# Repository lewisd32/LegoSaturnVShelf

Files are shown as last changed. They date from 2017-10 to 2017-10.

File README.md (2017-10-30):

# Lego Saturn V Shelf

This is a shelf for the [Lego Saturn V (21309)](https://shop.lego.com/en-CA/LEGO-NASA-Apollo-Saturn-V-21309),
made mostly out of Lego, with some 3D printed parts. Inspired by the [Saturn V Mobile Launcher Platform](http://www.savethelut.org/MLDocs/ap4-KSC-67PC-368.jpg), and it's gantry.
 
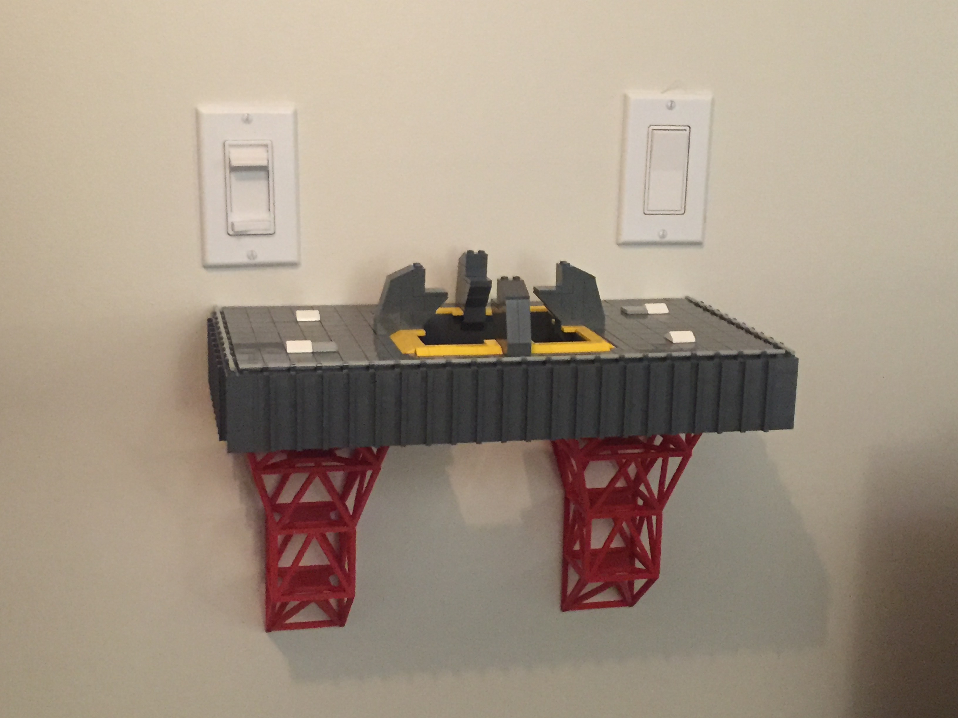
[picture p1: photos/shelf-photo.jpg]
photo of shelf

 
The only 3D printed parts are the screw mounts on the back, and the supports
underneath that are styled like the Saturn V gantry. Everything else is Lego.

## Lego Model

The model ([SaturnVShelf.lxf](SaturnVShelf.lxf)) can be opened with
[Lego Digital Designer](http://ldd.lego.com/en-us/)
4.3.

The included BOM ([SaturnVShelf-BOM.xlsx](SaturnVShelf-BOM.xlsx)) exported by LDD lists the pieces
needed. You can order most of the parts from [Pick-A-Brick](https://shop.lego.com/Pick-a-Brick).
The remainder can be had from [BrickLink](bricklink.com).

When I ordered pieces for this (June 2017) everything was available on Pick-A-Brick except for the
flat yellow tiles around the hole in the top. These were available on BrickLink.

## 3D Printing

Printing the gantry was, admittedly, a challenge. By separating each gantry
into 4 pieces, and further separating one of these pieces into 3 more, I was
able to print it successfully.

All files for 3D printing are within the [3D Printing](3DPrinting) folder. All the models
are done with [OpenSCAD](www.openscad.org).

- [shelf.scad](3DPrinting/shelf.scad) - Main rendering, and modules for all the gantry parts. 
- [rocket-bottom.scad](3DPrinting/rocket-bottom.scad) - Rough rendering of the bottom of the Lego Saturn V model. Only used for visualizing how the shelf will look.
- [screwmount.scad](3DPrinting/screwmount.scad) - Model for the part that holds the screws at the back of the shelf.

### Models

The [3DPrinting/prints](3DPrinting/prints) folder has the models for the gantry broken into individual parts for printing.
Both the OpenSCAD source file (`.scad`) and exported model (`.stl`) are included, so you shouldn't need OpenSCAD unless you
want to modify the models.
 
Gantry Layer 1 is split into 3 prints because I was unable to get it to print successfully as one piece. Your millage may vary.

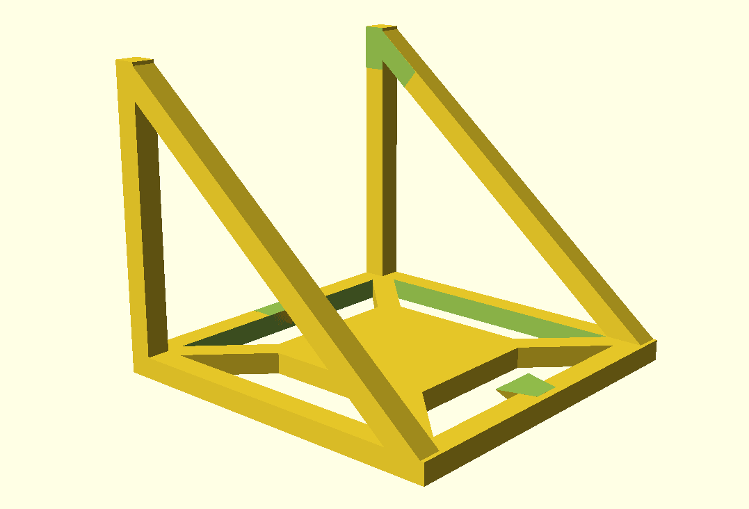
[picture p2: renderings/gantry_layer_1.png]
Gantry layer 1

[gantry_layer_1.stl](3DPrinting/prints/gantry_layer_1.stl)/[scad](3DPrinting/prints/gantry_layer_1.scad) - Lowest part of gantry, with center parts cut of for easier printing. 

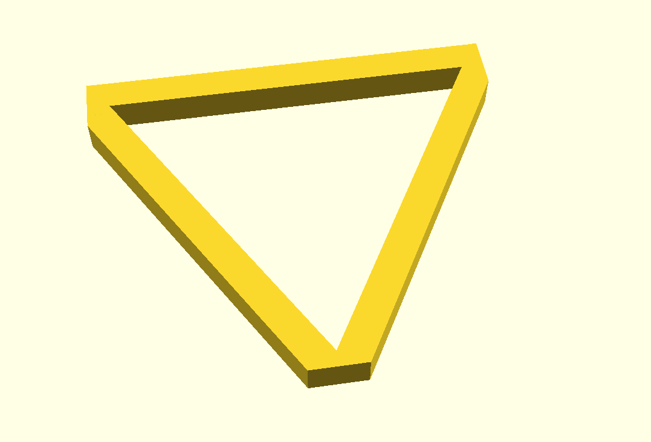
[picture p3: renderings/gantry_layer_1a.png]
Gantry layer 1 part a

[gantry_layer_1a.stl](3DPrinting/prints/gantry_layer_1a.stl)/[scad](3DPrinting/prints/gantry_layer_1a.scad) - One of the center parts.

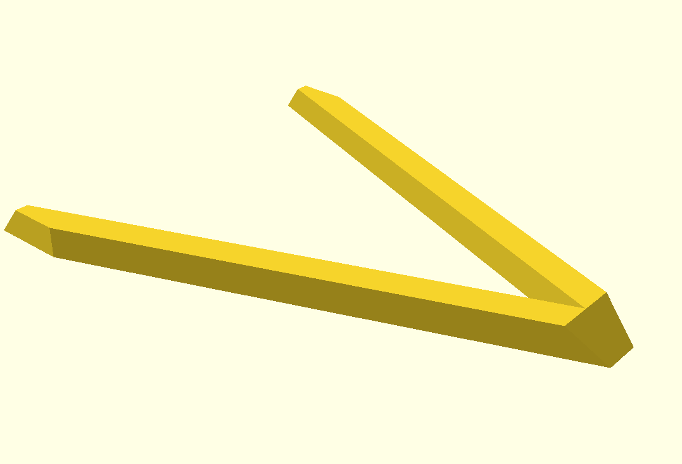
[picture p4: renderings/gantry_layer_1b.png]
Gantry layer 1 part b

[gantry_layer_1b.stl](3DPrinting/prints/gantry_layer_1b.stl)/[scad](3DPrinting/prints/gantry_layer_1b.scad) - The other center part.

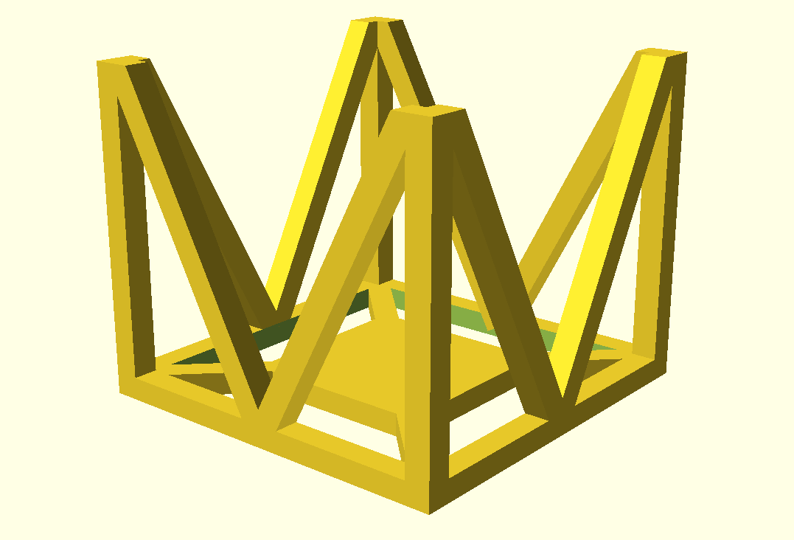
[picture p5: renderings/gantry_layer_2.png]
Gantry layer 2

[gantry_layer_2.stl](3DPrinting/prints/gantry_layer_2.stl)/[scad](3DPrinting/prints/gantry_layer_2.scad) - 2nd from bottom part of shelf. Straight sides, no angle. 

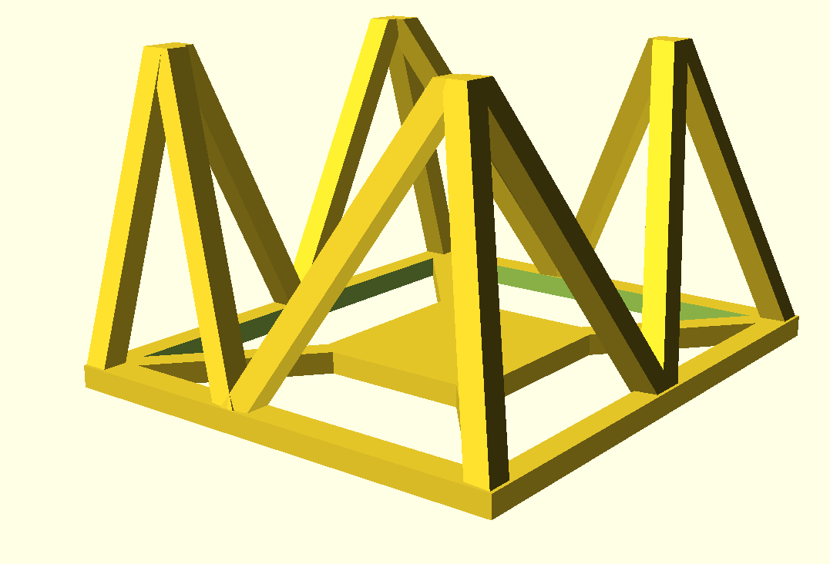
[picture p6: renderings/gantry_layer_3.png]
Gantry layer 2

[gantry_layer_3.stl](3DPrinting/prints/gantry_layer_3.stl)/[scad](3DPrinting/prints/gantry_layer_3.scad) - 2nd from top part of shelf, angled sides.

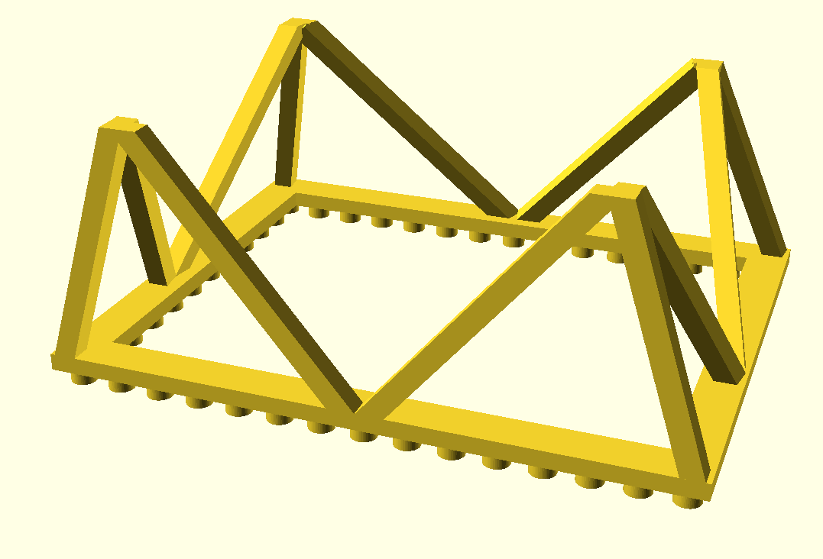
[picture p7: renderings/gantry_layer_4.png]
Gantry layer 3

[gantry_layer_4.stl](3DPrinting/prints/gantry_layer_4.stl)/[scad](3DPrinting/prints/gantry_layer_4.scad) - Top part of the gantry, with studs for mounting to the bottom of the shelf, and angled sides.

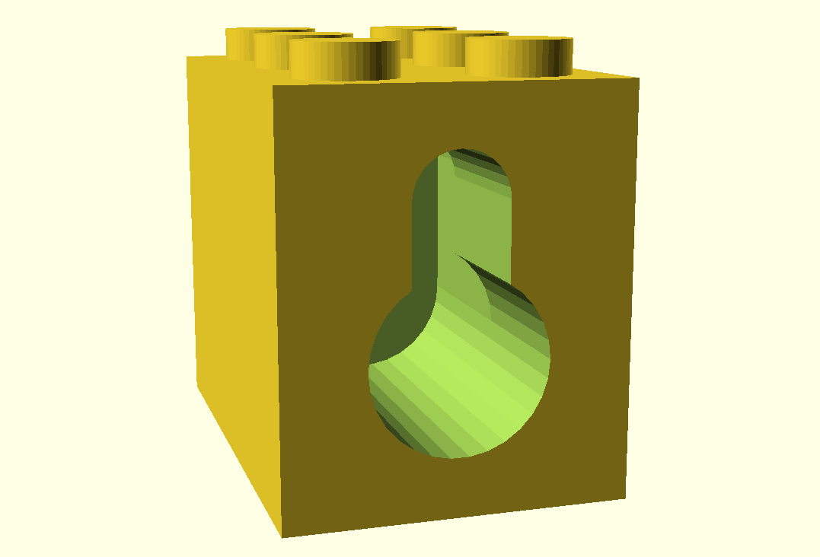
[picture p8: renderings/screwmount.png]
Screw mount

[screwmount.stl](3DPrinting/prints/screwmount.stl)/[scad](3DPrinting/prints/screwmount.scad) - Screw mounts for the back of the shelf. You'll need 3 of these.

### Printing

I printed this with ABS. This allows for using acetone to glue the different parts together quite strongly.

You'll need to figure out the best settings for your printer, but this is what I used:
- 0.4mm nozzle
- 0.1mm layers
- 100% infill
- 2.0mm wall thickness
- 1.2mm top/bottom thickness
- Inner before outer walls
- Support
  - Everywhere
  - 10 degree overhang angle
  - 15% density
  - 0.1mm Z distance (top and bottom)
  - 0.7mm X/Y distance 
- Raft
  - 5mm extra margin
  - 0.1mm air gap
  - 0.05mm initial z layer overlap
  - 2 top layers

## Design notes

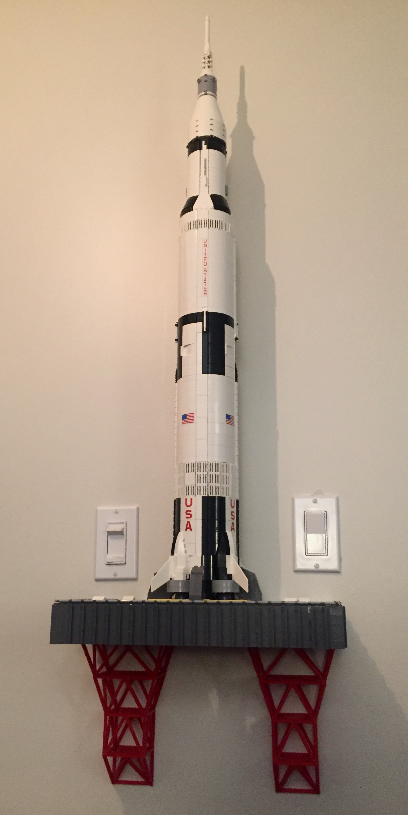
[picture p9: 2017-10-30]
photos/shelf-and-SaturnV-photo.jpg

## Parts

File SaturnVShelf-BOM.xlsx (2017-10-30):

Brick | Name | Picture | Part | Color code | Quantity
 | BRICK 1X1 |  | 3005 | 21 - Bright Red | 6
 | BRICK 1X1 |  | 3005 | 199 - Dark Stone Grey | 8
 | BRICK 1X2 |  | 3004 | 21 - Bright Red | 9
 | BRICK 1X2 |  | 3004 | 199 - Dark Stone Grey | 17
 | BRICK 1X3 |  | 3622 | 21 - Bright Red | 2
 | BRICK 1X2X2 |  | 3245 | 24 - Bright Yellow | 3
 | BRICK 2X2 |  | 3003 | 21 - Bright Red | 10
 | BRICK 2X2 |  | 3003 | 199 - Dark Stone Grey | 20
 | BRICK 1X4 |  | 3010 | 21 - Bright Red | 8
 | BRICK 1X4 |  | 3010 | 199 - Dark Stone Grey | 2
 | BRICK 2X3 |  | 3002 | 21 - Bright Red | 12
 | BRICK 2X3 |  | 3002 | 199 - Dark Stone Grey | 63
 | BRICK 1X6 |  | 3009 | 21 - Bright Red | 8
 | BRICK 1X6 |  | 3009 | 199 - Dark Stone Grey | 43
 | BRICK 2X4 |  | 3001 | 21 - Bright Red | 170
 | BRICK 2X4 |  | 3001 | 199 - Dark Stone Grey | 154
 | BRICK 1X8 |  | 3008 | 21 - Bright Red | 3
 | BRICK 1X8 |  | 3008 | 199 - Dark Stone Grey | 2
 | BRICK 1X10 |  | 6111 | 21 - Bright Red | 8
 | BRICK 1X10 |  | 6111 | 199 - Dark Stone Grey | 2
 | BRICK 2X6 |  | 44237 | 21 - Bright Red | 2
 | BRICK 2X6 |  | 44237 | 199 - Dark Stone Grey | 23
 | ROOF TILE 1X1X2/3, PC |  | 50746 | 24 - Bright Yellow | 8
 | ROOF TILE 1 X 2 X 2/3, ABS |  | 85984 | 1 - White | 16
 | ROOF TILE 1 X 2 X 2/3, ABS |  | 85984 | 24 - Bright Yellow | 24
 | ROOF TILE 2X2/45 INV. |  | 3660 | 199 - Dark Stone Grey | 12
 | ROOF TILE 1X2X3/73° |  | 4460 | 199 - Dark Stone Grey | 8
 | ROOF TILE 2X3/25° |  | 3298 | 199 - Dark Stone Grey | 4
 | FLAT TILE 1X1 |  | 3070 | 24 - Bright Yellow | 4
 | FLAT TILE 1X1 |  | 3070 | 199 - Dark Stone Grey | 16
 | PLATE 1X1 |  | 3024 | 1 - White | 2
 | PLATE 1X1 |  | 3024 | 199 - Dark Stone Grey | 72
 | FLAT TILE 1X2 |  | 3069 | 24 - Bright Yellow | 28
 | FLAT TILE 1X2 |  | 3069 | 199 - Dark Stone Grey | 20
 | PLATE 1X2 |  | 3023 | 21 - Bright Red | 6
 | PLATE 1X2 |  | 3023 | 199 - Dark Stone Grey | 14
 | FLAT TILE 1X4 |  | 2431 | 199 - Dark Stone Grey | 1
 | FLAT TILE 2X2 |  | 3068 | 194 - Medium Stone Grey | 4
 | FLAT TILE 2X2 |  | 3068 | 199 - Dark Stone Grey | 176
 | PLATE 2X2 |  | 3022 | 21 - Bright Red | 6
 | PLATE 2X2 |  | 3022 | 199 - Dark Stone Grey | 4
 | PLATE 1X4 |  | 3710 | 1 - White | 2
 | PLATE 1X4 |  | 3710 | 21 - Bright Red | 4
 | PLATE 1X4 |  | 3710 | 199 - Dark Stone Grey | 29
 | FLAT TILE 1X6 |  | 6636 | 199 - Dark Stone Grey | 23
 | PLATE 1X6 |  | 3666 | 1 - White | 2
 | PLATE 1X6 |  | 3666 | 21 - Bright Red | 12
 | PLATE 1X6 |  | 3666 | 199 - Dark Stone Grey | 14
 | PLATE 2X4 |  | 3020 | 199 - Dark Stone Grey | 4
 | PLATE 1X8 |  | 3460 | 1 - White | 2
 | PLATE 1X12 |  | 60479 | 1 - White | 3
 | PLATE 1X1 W. HOLDER |  | 4085 | 199 - Dark Stone Grey | 65
 | PLATE 1X2 WITH SLIDE |  | 32028 | 199 - Dark Stone Grey | 123
 | PLATE 1X2 W. STICK |  | 2540 | 1 - White | 24
 | LIGHT SWORD - BLADE |  | 30374 | 194 - Medium Stone Grey | 23
Total:

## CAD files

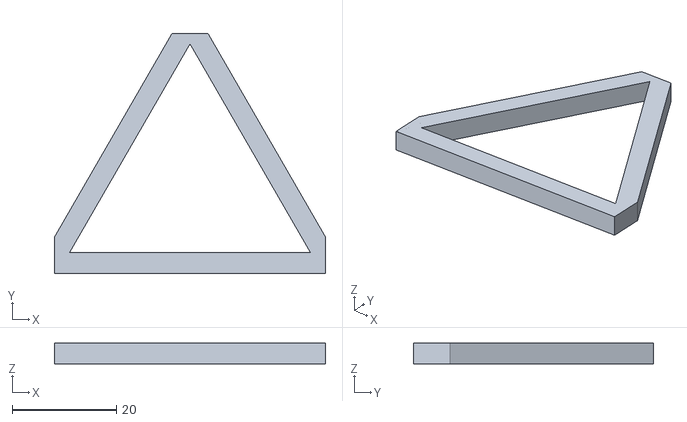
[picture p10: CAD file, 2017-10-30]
3DPrinting/prints/gantry_layer_1a.stl
52.0 x 46.0 x 4.01

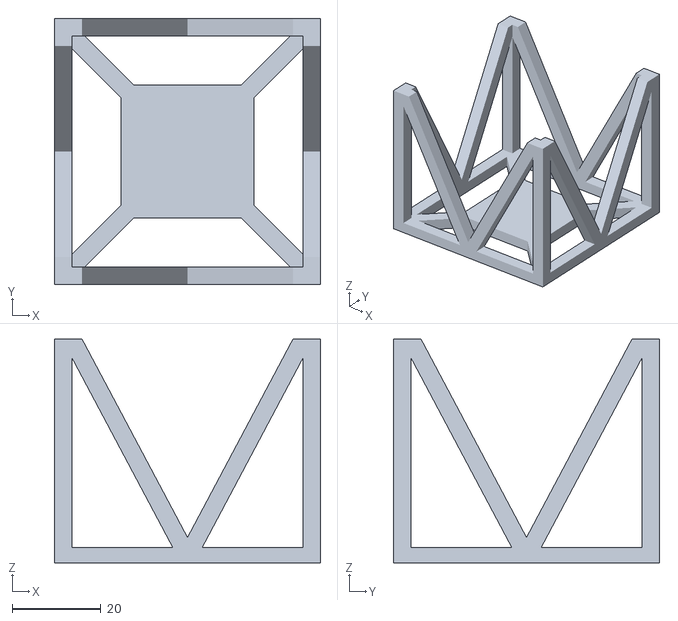
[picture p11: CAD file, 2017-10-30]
3DPrinting/prints/gantry_layer_2.stl
60.0 x 60.0 x 50.5

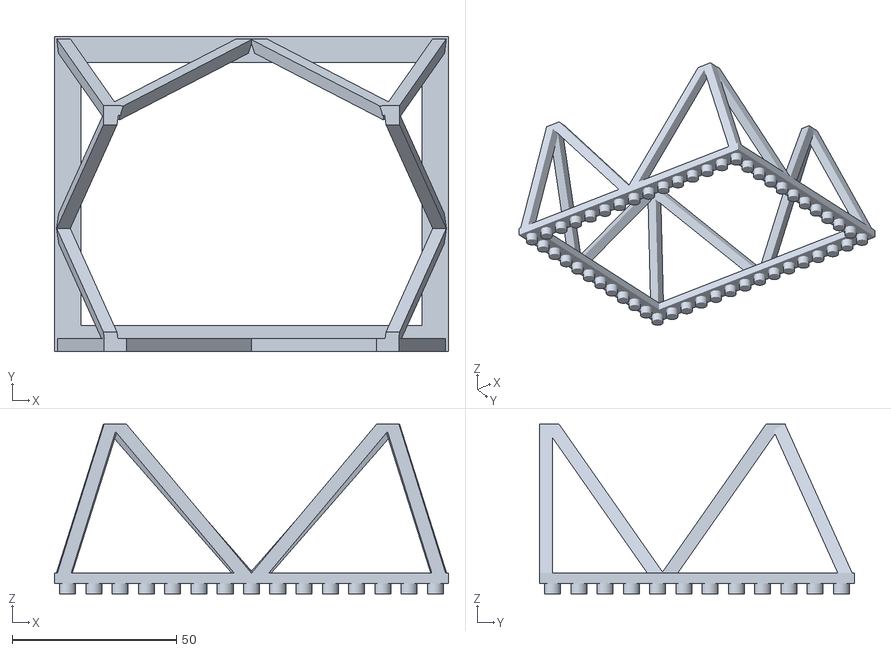
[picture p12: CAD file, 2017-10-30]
3DPrinting/prints/gantry_layer_4.stl
120.0 x 96.0 x 51.7

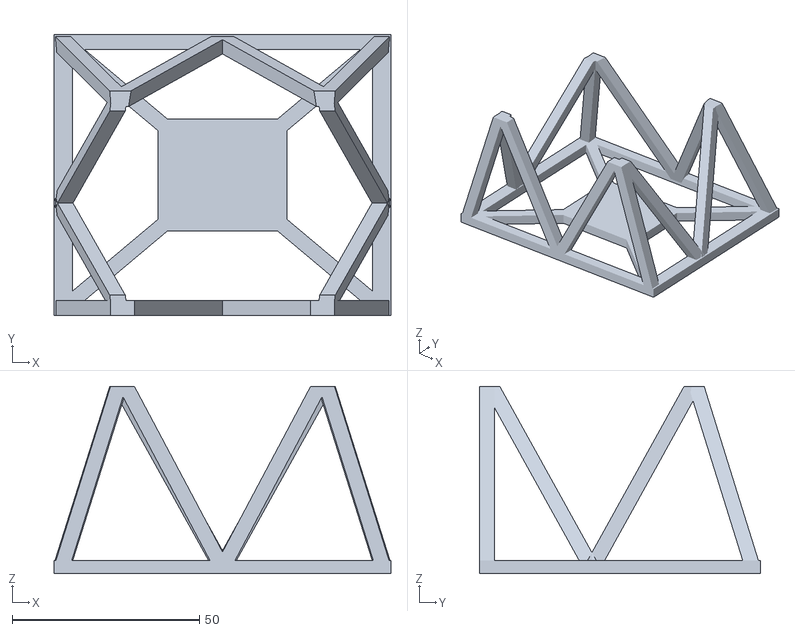
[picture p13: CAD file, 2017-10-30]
3DPrinting/prints/gantry_layer_3.stl
90.0 x 75.0 x 50.0

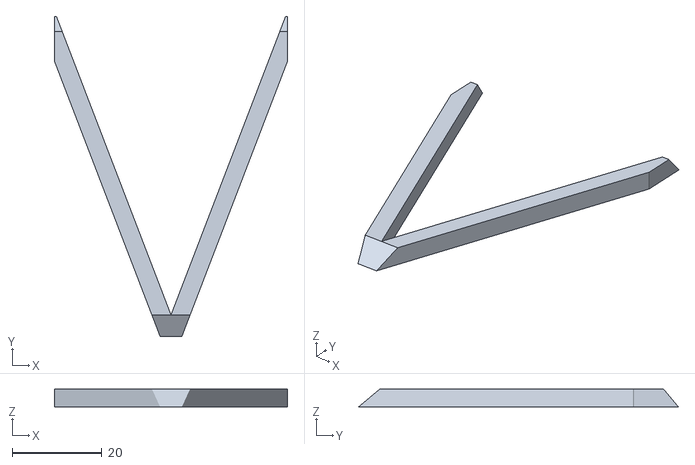
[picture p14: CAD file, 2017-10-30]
3DPrinting/prints/gantry_layer_1b.stl
52.0 x 71.4 x 4.00

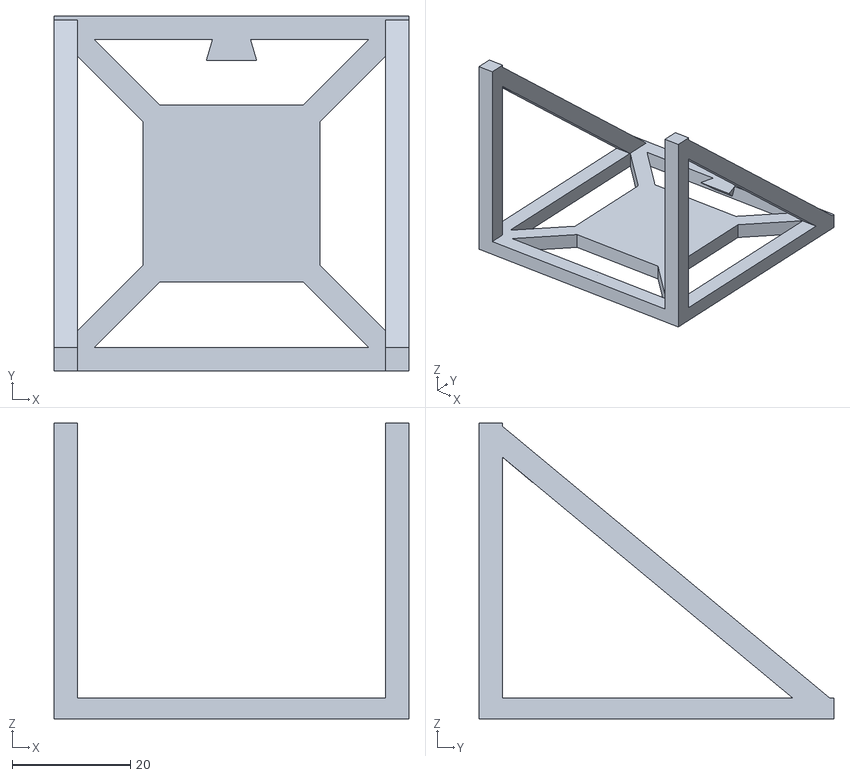
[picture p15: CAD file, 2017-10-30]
3DPrinting/prints/gantry_layer_1.stl
60.0 x 60.0 x 50.0

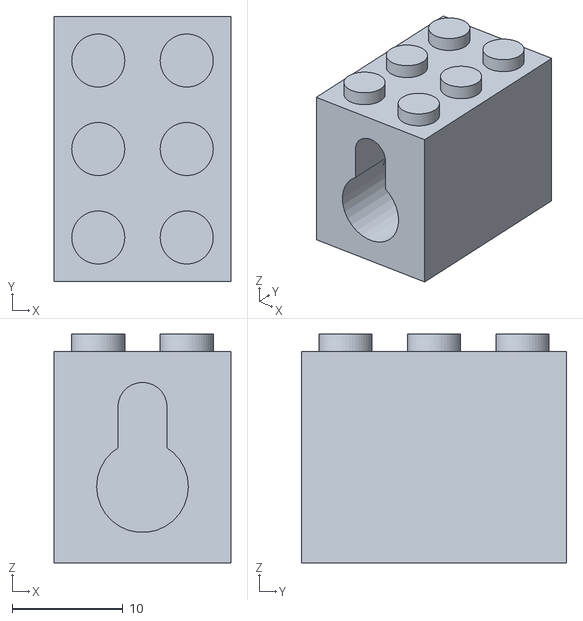
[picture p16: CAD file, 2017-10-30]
3DPrinting/prints/screwmount.stl
16.0 x 24.0 x 20.7

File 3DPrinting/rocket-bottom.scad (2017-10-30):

use <lib/centered_cube.scad>
use <lib/torus.scad>

translate([0,0,-1.1])
ccube([93,93,1]);

module nozzle() {
    color([.2,.2,.2])
    cylinder(d1=40, d2=16+(40-16)*((40-16)/40), h=16);

    color([.35,.35,.35])
    translate([0,0,16])
    torus(34, 5);

    color([.5,.5,.5])
    translate([0,0,16])
    cylinder(d1=16+(40-16)*((40-16)/40), d2=16, h=40-16);
}


module nozzle_and_fin() {
    nozzle();

    color([.8, .8, .8])
    translate([0,0,41.6]) {
        intersection() {
            cylinder(d=38, h=16);
            translate([0,0,-1])
            ccube([50,50,20], centered=[0,1,0]);
        }
        rotate([0,0,180])
        ccube([4,38,16], centered=[0,1,0]);
    }
    
    color([0,0,0])
    translate([0,0,40])
    ccube([16, 16, 8], centered=[1,1,0]);


    // fin mount
    color([1,1,1])
    translate([0,0,57.6])
    resize([38,32,64])
    cylinder(d1=32, d2=16, h=64);

    // fin
    color([1,1,1])
    translate([18,0,65.6])
    rotate([90,0,0])
    translate([0,0,-0.8])
    linear_extrude(height=1.6) {
        polygon(points=[
            [0,0],
            [3,-8],
            [32, -22],
            [32, -6],
            [0, 24]
        ]);
    }
}

module rocket_bottom() {
    nozzle();
    color([.8, .8, .8])
    translate([0,0,40])
    cylinder(d=16, h=18);

    for (r = [0:1:3]) {
        rotate([0,0,r*90])
        translate([42.5,0,0])
        nozzle_and_fin();
    }
    
    // bottom of fuel tank
    color([1,1,1])
    translate([0,0,58])
    cylinder(d=80, h=32);
}

rocket_bottom();

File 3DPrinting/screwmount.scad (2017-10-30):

use <lib/centered_cube.scad>
use <lib/lego_brick_builder.scad>

screw_head_diameter=8.1 + 0.1;
screw_head_height=3.5;
screw_thread_diameter=4.25 + 0.1;

screw_ledge_depth=7.5;

FLU = 1.6; // Fundamental Lego Unit = 1.6 mm

BRICK_WIDTH = 5*FLU; // basic brick width
BRICK_HEIGHT = 6*FLU;
PLATE_HEIGHT = 2*FLU; // basic plate height

difference() {
    union() {
        translate([0,0,PLATE_HEIGHT])
        ccube([BRICK_WIDTH*2, BRICK_WIDTH*3, BRICK_HEIGHT*2 - PLATE_HEIGHT], centered=[1,0,0]);
        
        translate([-BRICK_WIDTH,0,-0.3])
        brick(2,3,1.25,1);

        translate([-BRICK_WIDTH,0,BRICK_HEIGHT*2])
        brick(2,3,0,0);
    }
    
    translate([0,0,-0.31])
    ccube([BRICK_WIDTH*2+1, BRICK_WIDTH*3+1, 0.4], centered=[1,0,0]);

    // hole for screw thread
    hull() {
        translate([0,-0.01,BRICK_HEIGHT*2-5])
        rotate([-90,0,0])
        cylinder(d=screw_thread_diameter+0.1, h=screw_ledge_depth+screw_head_height+5, $fs=0.5);

        translate([0,-0.01,7])
        rotate([-90,0,0])
        cylinder(d=screw_thread_diameter+0.1, h=screw_ledge_depth+screw_head_height+5, $fs=0.5);
    }

    // inner hole for screw head
    hull() {
        translate([0,screw_ledge_depth,BRICK_HEIGHT*2-5])
        rotate([-90,0,0])
        cylinder(d=screw_head_diameter+0.1, h=screw_head_height+5, $fs=0.5);

        translate([0,screw_ledge_depth,7])
        rotate([-90,0,0])
        cylinder(d=screw_head_diameter+0.1, h=screw_head_height+5, $fs=0.5);
    }
    
    // outer hole for screw head
        translate([0,-0.01,7])
        rotate([-90,0,0])
        cylinder(d=screw_head_diameter+0.1, h=screw_ledge_depth+screw_head_height+5, $fs=0.5);

}


/*
translate([-FLU*2.5,FLU*2.5,-0.1])
cylinder(d=FLU*3, h=FLU, $fn=50);

*/

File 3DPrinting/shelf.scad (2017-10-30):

use <lib/centered_cube.scad>
use <lib/lego_brick_builder.scad>
use <rocket-bottom.scad>

do_slow=true;

FLU = 1.6; // Fundamental Lego Unit = 1.6 mm

BRICK_WIDTH = 5*FLU; // basic brick width
BRICK_HEIGHT = 6*FLU;
PLATE_HEIGHT = 2*FLU; // basic plate height

rib_thickness=3;
rib_depth=4;
rib_spacing=20.5;

lip_thinckness=3;
lip_depth=rib_depth;

platform_x = 366;
platform_y = 180;
platform_z = 50;

module platform_with_ribs() {
    color([.8,.8,.8]) {

    ccube([platform_x,platform_y,platform_z], centered=[1,1,0]);
        
    // fill in the ribs at the back of the platform so they 
    // don't gouge the wall.
    translate([0,-platform_y/2-rib_depth,0])
    ccube([platform_x,rib_depth*2,platform_z], centered=[1,0,0]);

    // corners
    for (x = [-platform_x/2, platform_x/2]) {
        for (y = [-platform_y/2, platform_y/2]) {
            translate([x, y, 0])
            ccube([rib_depth*2,rib_depth*2,platform_z], centered=[1,1,0]);
        }
    }

    for (y = [-platform_y/2, platform_y/2]) {
        // top and bottom lip at front of platform
        for (z = [0, platform_z-lip_thinckness]) {
            translate([0,y,z])
            ccube([platform_x,lip_depth*2,lip_thinckness], centered=[1,1,0]);
        }

        // ribs at front (and back) of platform
        for (x = [-platform_x/2:rib_spacing:platform_x/2]) {
            translate([x, y, 0])
                ccube([rib_thickness,rib_depth*2,platform_z], centered=[1,1,0]);
        }
    }

    for (x = [-platform_x/2, platform_x/2]) {
        // top and bottom lip at sides of platform
        for (z = [0, platform_z-lip_thinckness]) {
            translate([x,0,z])
            ccube([lip_depth*2,platform_y,lip_thinckness], centered=[1,1,0]);
        }

        // ribs on sides of platform
        for (y = [-platform_y/2:rib_spacing:platform_y/2]) {
            translate([x, y, 0])
                ccube([rib_depth*2,rib_thickness,platform_z], centered=[1,1,0]);
        }
    }

    }
}

module wedge() {
    hull() {
        cube([1,1,0.1]);
        cube([0.1,1,1]);
    }
}

module lego_double_wedge() {
    translate([-BRICK_WIDTH, 0, 0])
    brick(2,1,1,1);
    *translate([-BRICK_WIDTH, 0, 0])
    brick(1,1,1,1);
    translate([BRICK_WIDTH, 0, 0])
    resize([BRICK_WIDTH, BRICK_WIDTH, PLATE_HEIGHT])
    wedge();
    
    translate([BRICK_WIDTH-0.5, 0, 0])
    cube([1,BRICK_WIDTH,1]);
}

module lego_wedge() {
    brick(1,4,1,1);
    translate([BRICK_WIDTH, 0, 0])
    resize([BRICK_WIDTH*1, BRICK_WIDTH*4, PLATE_HEIGHT])
    wedge();
    
    translate([BRICK_WIDTH-0.5, 0, 0])
    cube([1,BRICK_WIDTH*4,1]);
}

module lego_corner_wedge() {
    translate([-BRICK_WIDTH, 0, 0])
    difference() {
        brick(2,1,1,1);
        translate([1.6+BRICK_WIDTH,6,-1])
        cube([4.8,3,2.6]);
    }
    
    difference() {
        brick(1,2,1,1);
        translate([-0.5,1.6,-1])
        cube([3,4.8,2.6]);
    }
    
    
    translate([BRICK_WIDTH, 0, 0])
    resize([BRICK_WIDTH*1, BRICK_WIDTH*2, PLATE_HEIGHT])
    wedge();
    
    translate([-BRICK_WIDTH, 0, 0])
    rotate([0,0,-90])
    resize([BRICK_WIDTH*1, BRICK_WIDTH*2, PLATE_HEIGHT])
    wedge();

    intersection() {
        translate([BRICK_WIDTH, -BRICK_WIDTH, 0])
        resize([BRICK_WIDTH*1, BRICK_WIDTH*1, PLATE_HEIGHT])
        wedge();
        
        translate([BRICK_WIDTH, 0, 0])
        rotate([0,0,-90])
        resize([BRICK_WIDTH*1, BRICK_WIDTH*1, PLATE_HEIGHT])
        wedge();
    }
    
    translate([BRICK_WIDTH-0.5, 0, 0])
    cube([1,BRICK_WIDTH*2,1]);
    
    translate([-BRICK_WIDTH, -0.5, 0])
    cube([BRICK_WIDTH*2, 1,1]);

}

module yellow_outlines() {
    for (r = [0:1:3]) {
        rotate([0,0,r*90])
        translate([55,-55,platform_z]) {
            corner_d=5;
            w=50;
            l=10;
            t=7;
            h=1;
            o=1;
            
            color([.8,.8,0])
            translate([0, BRICK_WIDTH, 0])
            lego_wedge();
                
            color([.85,.85,0])
            translate([0, BRICK_WIDTH*5, 0])
            lego_double_wedge();

            color([.85,.85,0])
            translate([0, -BRICK_WIDTH, 0])
            lego_corner_wedge();

            color([.85,.85,0])
            mirror([1,1,0])
            translate([0, BRICK_WIDTH*5, 0])
            lego_double_wedge();

            color([.8,.8,0])
            mirror([1,1,0])
            translate([0, BRICK_WIDTH, 0])
            lego_wedge();
        }
    }
}

module flame_channels() {
    for (r = [0:1:3])
    rotate([0,0,r*90])
    translate([BRICK_WIDTH*4,BRICK_WIDTH*4,-1])
    ccube([BRICK_WIDTH*6, BRICK_WIDTH*6,200], centered=[1,1,0]);
    
    hull() {
        translate([0,0,-1])
        ccube([BRICK_WIDTH*14, BRICK_WIDTH*14, 1], centered=[1,1,0]);
        translate([0,0,platform_z-PLATE_HEIGHT])
        ccube([BRICK_WIDTH*10, BRICK_WIDTH*10, 0.01], centered=[1,1,0]);
    }
    translate([0,0,platform_z-PLATE_HEIGHT])
    ccube([BRICK_WIDTH*10, BRICK_WIDTH*10, PLATE_HEIGHT*2], centered=[1,1,0]);
}

module hold_down_arm() {
    translate([BRICK_WIDTH*5,-BRICK_WIDTH,platform_z]) {
        color([.8,.8,.8])
        brick(4, 2, 3);

        color([1,1,1])
        translate([BRICK_WIDTH,0,BRICK_HEIGHT])
        brick(3, 2, 3);
        color([.9,.9,.9])
        translate([-BRICK_WIDTH,0,BRICK_HEIGHT])
        brick(2, 2, 3);
        

        color([.8,.8,.8])
        translate([-BRICK_WIDTH*2,0,BRICK_HEIGHT*2])
        brick(2, 2, 3);
        color([.9,.9,.9])
        translate([0,0,BRICK_HEIGHT*2])
        brick(3, 2, 3);
        
        color([.8,.8,.8])
        translate([-BRICK_WIDTH*2,0,BRICK_HEIGHT*3])
        brick(1, 2, 1, 1);
        color([.7,.7,.7])
        translate([-BRICK_WIDTH,0,BRICK_HEIGHT*3])
        brick(2, 2, 1, 1);
        color([1,1,1])
        translate([BRICK_WIDTH*1,0,BRICK_HEIGHT*3])
        brick(1, 2, 3);
        color([.8,.8,.8])
        translate([BRICK_WIDTH*2,0,BRICK_HEIGHT*3])
        brick(1, 2, 3);

        color([.8,.8,.8])
        translate([0,0,BRICK_HEIGHT*3+PLATE_HEIGHT])
        brick(1, 2, 2);
        
        color([.9,.9,.9])
        translate([0,0,BRICK_HEIGHT*4])
        brick(3, 2, 3);
    }
}

module hold_down_arms() {
    for (r = [0:1:3])
    rotate([0,0,r*90])
    hold_down_arm();
}

module launch_platform() {
    difference() {
        union() {
            platform_with_ribs();
            if (do_slow) {
                lego_plate();
            }
        }
        flame_channels();

        // Cut it in half to visualize the interior
        // of the flame channels
        *ccube([500, 500, 500], centered=[0,1,1]);
    }
}

module lego_plate() {
    color([.8,.8,.8])
    for (r = [0:1:3])
    rotate([0,0,r*90])
    translate([-BRICK_WIDTH,BRICK_WIDTH*5,platform_z-PLATE_HEIGHT]) {

        // hold down arms attachment
        brick(2, 4, 1);
        
        // yellow outlines attachment
        translate([-BRICK_WIDTH*7, BRICK_WIDTH*2, 0])
        brick(15, 1, 1);
    }
}

// gantry settings
g_d=60;
g_t=4;

module gantry_layer1() {
    // horizontal braces
    translate([0,0,-150])
    difference() {
        ccube([g_d, g_d, g_t]);
        translate([0,0,-g_t/4])
        ccube([g_d-g_t*2, g_d-g_t*2, g_t*2]);
    }
    
    // platform
    translate([0,0,-150])
    ccube([g_d/2, g_d/2, g_t]);

    // platform braces
    translate([0,0,-150]){
        for (r = [0:1:3])
        rotate([0,0,r*90+45])
        ccube([40,g_t,g_t], centered=[0,1,1]);
    }

    // vertical verticals
    for (m = [0,1])
    mirror([m,0,0]) 
    translate([g_d*0.5-g_t/2, -g_d/2 + g_t/2, -150])
    rotate([0,90,0])
    ccube([48.6, g_t, g_t], centered=[0,1,1]);

    for (m = [0,1])
    mirror([m,0,0]) 
    translate([g_d*0.5-g_t/2, g_d*0.5-g_t/2+0.6, -150])
    rotate([-50.3,0,0])rotate([0,90,0])
    ccube([74.2, g_t, g_t], centered=[0,1,1]);

    // front/rear angled supports between "verticals"
    for (m = [0,1])
    mirror([m,0,0]) 
    translate([0, -g_d/2 + g_t/2, -150])
    rotate([0,60,0])
    ccube([55, g_t, g_t], centered=[0,1,1]);

    for (m = [0,1])
    mirror([m,0,0]) 
    translate([0, -g_d/2 + g_d-g_t/2, -150])
    rotate([-50,0,0])
    rotate([0,69,0])
    ccube([79, g_t, g_t], centered=[0,1,1]);



    // horizontal brace, against wall, very bottom
    translate([-g_d*0.5, -g_d/2, -200 + g_t])
    ccube([g_d, g_t, g_t], centered=[0,0,1]);
}

module gantry_layer2() {
    // horizontal braces
    translate([0,0,-100])
    difference() {
        ccube([g_d, g_d, g_t]);
        translate([0,0,-g_t/4])
        ccube([g_d-g_t*2, g_d-g_t*2, g_t*2]);
    }

    // platform
    translate([0,0,-100])
    ccube([g_d/2, g_d/2, g_t]);

    // platform braces
    translate([0,0,-100]){
        for (r = [0:1:3])
        rotate([0,0,r*90+45])
        ccube([40,g_t,g_t], centered=[0,1,1]);
    }
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

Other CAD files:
3DPrinting/prints/gantry_layer_1.scad
3DPrinting/prints/gantry_layer_1a.scad
3DPrinting/prints/gantry_layer_1b.scad
3DPrinting/prints/gantry_layer_2.scad
3DPrinting/prints/gantry_layer_3.scad
3DPrinting/prints/gantry_layer_4.scad
